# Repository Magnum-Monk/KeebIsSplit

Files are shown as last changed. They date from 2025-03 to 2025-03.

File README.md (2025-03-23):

### Keeb Is Split

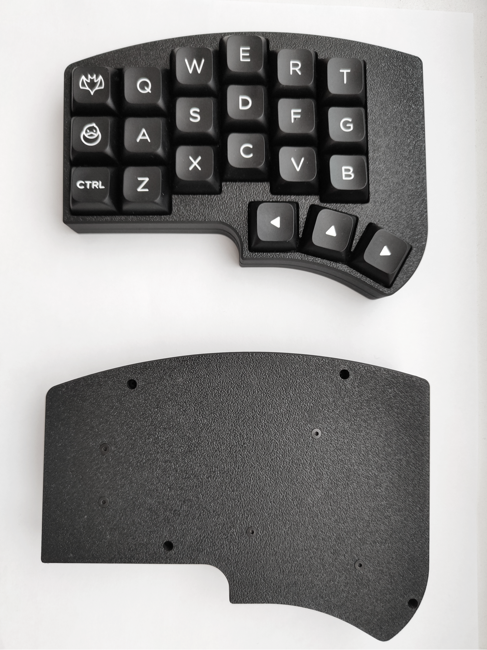
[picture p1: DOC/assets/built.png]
built

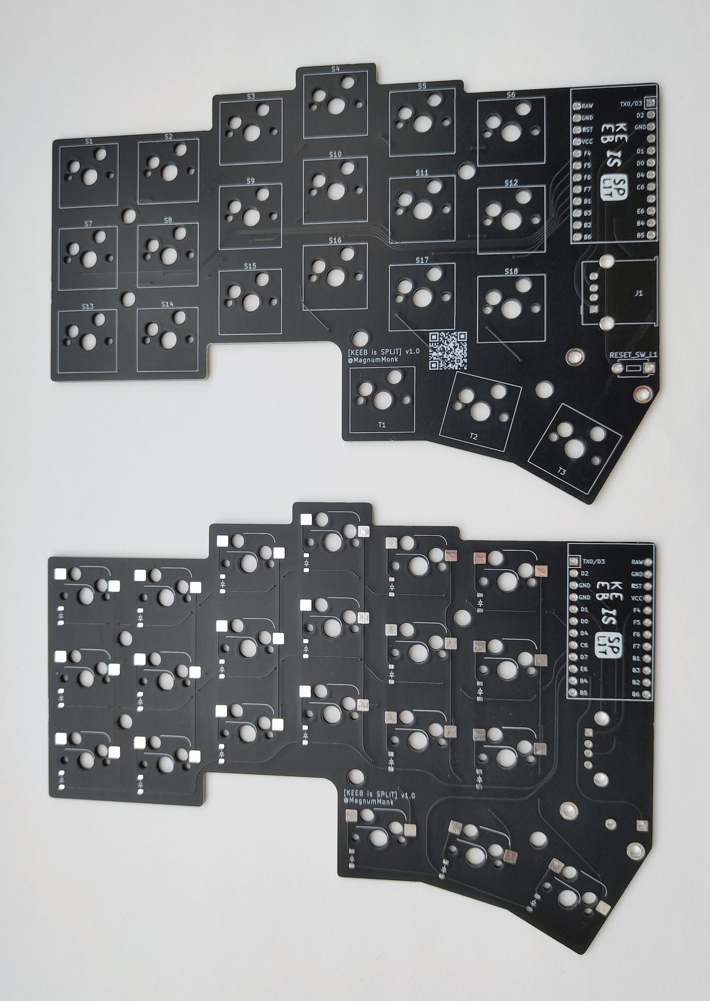
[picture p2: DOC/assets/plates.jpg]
plates


#### Whats the big idea? (TLDR)
Robust, decent-looking, comfortable, cost-effective, easy-to-build/repair/use 3x6 split keyboard. 

#### References / Credits / Inspirations :
- [**CRKBD**](https://github.com/foostan/crkbd) - all-time classic, "industry standart" of DIY ergo keyboards at this point, if I could say so myself;
- [**Cantor/Piantor**](https://github.com/diepala/cantor) - excellent thumb cluster, overall big improvement in layout ergonimics imo.
- [**Altair/Altair-X**](https://www.reddit.com/r/MechanicalKeyboards/comments/1cg4ejp/gb_altairx_live_now_a_premium_easy_to_learn/) - top grade aestethics, build quality.
- [**Cheapino**](https://github.com/tompi/cheapino) - Robust, easy to assemble, easy to fix/repair, easy to source components, well... cheap! ☺️

#### Firmware
This build utilizes exact pinout that **CRKBD** uses. So you can safely use your Corne (v2/v3) firmware to flash this keyboard.
If you've never had a Corne keyboard before, [this](https://github.com/fathulfahmy/corne-keyboard/tree/main/firmware) should work

#### Build guide 
[here](https://github.com/Magnum-Monk/KeebIsSplit/blob/main/DOC/build_guide.md)

#### BOM
| Part | Amount | Links |
|---|---|---|
| ProMicro-like MCU | 2 | [aliexpress](https://aliexpress.com/item/1005004242820623.html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) |
| PCB | 2 | JLCPCB, PCBWay or other service that you prefer |
| MX HotSwap Socket | 42 | [aliexpress](https://aliexpress.com/wholesale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) |
| SMD SOD123 Diode | 42 | [aliexpress](https://www.aliexpress.com/w/wholesale-sod-123-1n4148.html?spm=a2g0o.detail.auto_suggest.3.49e124bT24bTMs) |
| USB-A Socket | 2 | [aliexpress](https://aliexpress.com/item/1005006501690133.html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) |
| USB-A -> USB-A Cable | 1 | [aliexpress 1](https://aliexpress.com/item/1005003574732583.html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) [aliexpress 2](https://aliexpress.com/item/1005006002851777.html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)  [aliexpress 3](https://aliexpress.com/item/1005007351594401.html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) |
| Reset Button | 2 | [aliexpress](https://aliexpress.com/item/1005007177692594.html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) |
| Header Pin Sockets (20 pin) | 4 | [aliexpress](https://aliexpress.com/item/1005005104952508.html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) |
| M2x5 screw | 20 | For attaching mounting plate and bottom case |
| M2x6 screw | 8 | For attaching top case to bottom case |
| M2x5 spacer | 18 | [aliexpress](https://aliexpress.com/item/4000314663724.html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) |
| Top case left | 1 | |
| Top case right | 1 | |
| Bottom case left | 1 | |
| Bottom case right | 1 | |
| Mounting plate left | 1 | |
| Mounting plate right | 1 | |
| Foam mid | 2 | |
| Foam bottom | 2 | |

#### "Why won't you just use one of those referenced options?"
(Basically, a list of nit-picks 😀 )
- **CRKBD** - thumb cluster, specifically 1.5u outermost keys. Not only does it feel a bit clunky for me to use, but also, finding matching keycaps for those keys could be challenging and annoying (and convex 1.5u spacebar is a rarity of its own kind). Although I do somewhat understand the reasoning behind this (design-wise, it makes sense to extend this key to 1.5u, because with 1u you kind of have this "weird" empty corner between this key and the MCU, which for some may look off-putting. Since the mcu is quite wide, you cannot eliminate this issue without moving the whole cluster outwards or rotating it in a werid position, which in and of itself could hurt comfort of use. TRRS connection between two halves.
> Since TRRS safety is quite sensitive and reoccuring topic in the DIY-keyboards community I will not touch it here (or will I?), but I would avoid this option if possible.

- **Cantor / Piantor** - although it is very comfortable to use layout-wise, the MCU board itself is huge, albeit much easier to flash. Which in turn somewhat leaves it with the only option for the halves connection to also be TRRS.
- **Altair/Altair-X** - Not open source. Difficult to repair, if something "dies".  Good luck finding available one to buy these days 😀, not to mention hefty price tag.
- **Cheapino** - RJ45 might be too janky-looking and overall big connector for some users (me included), Otherwise very cool and build-friendly board 🥰.

#### Why not low-profile?

Well, mostly the switches. I am yet to find LP switch, that can compete in typing feel with some remarkable and widely loved MX-type ones. And I have tried almost all chocs, a variety of KS33 and Kailh LP models. The available selection of MX switches at this point is far more superior imo, and could fulfill the needs of any enthusiast. 

#### Why not wireless?
I've tried multiple wireless keyboards, and keeping their charge levels in check is just another hassle for me. And the batteries themselves being another point of failure (experienced quite a few "spicy pillows" myself), which defeats the goal of this being robust. Maybe in the future I'll rethink this, but with the use of 3.7v AAA or coin cell batteries as a power source.

#### Why no LEDs?
I mean... Nothing against it, but it adds nothing of value to the device imo, except, well, cost and build complexity.

#### Why no OLEDs?
Again, I fiddled with them for some time in my Corne keyboards, but at the end I just removed them for the purpose of fitting in a slimmer case. How often do you look at them anyway, while using your device? They're okay to help debugging some build issues with the keyboard, but other than than, just "bells and whistles".

#### Why USB-A connectors? (Oops, I couldn't help myself)

Although its highly debatable, I still think this is the "safe-ish" option to connect two halves of a keyboard:
- Hot pluggable. Finally, no fear of accidentally detaching the cable from your keyboard and frying GPIO, or the whole MCU.
- Low-ish chance of connecting it to the wrong device accidentally, since finding spare USB-A to USB-A cable lying on your desk, connected to some of your devices is highly unlikely (not the case with USB-c, for example). Not to mention, using the same port type to connect keyboard to PC and left MCU to the right MCU can be somewhat confusing, and could easily result in  some MCU damage, being connected improperly).

> But still, please do not use USB-A port on this keyboard to anything other than connecting two halves together. Connecting it to, say, USB port on your PC would most likely damage your MCU, since standard USB port supplies 5v, and MCU is expecting 3.3v.

- Although the selection of available cables is much more limited, than, say, TRRS, there are a lot of options still. And If nothing fits your bill, there are a lot of connectors available to build your own custom cable.

Overall, designing circuitry that supports bi-directional data/power flow with reliable and resilient MCU protection is a challenging task (quite beyond my expertise, tbh), and will definitely significantly complicate assembling process and increase the amount of parts needed (and the price, which is definitely an important factor too).

#### KiCad symbol/footprint libraries used:
- Mostly [scottokeebs](https://github.com/joe-scotto/scottokeebs/tree/main "scottokeebs") ones. Huge props to the guy!
- Also [foostan's](https://github.com/foostan/kbd/tree/f90510c11b6df53bcdb55740b0d59183957e4036) ones

Unfortunately, all 3D files are made in SolidWorks, which is not free/opensource. Maybe someday I'll redo them in FreeCad, but for now it is what it is. STP files for 3D printing (which most slicers should support nowadays) are also included.

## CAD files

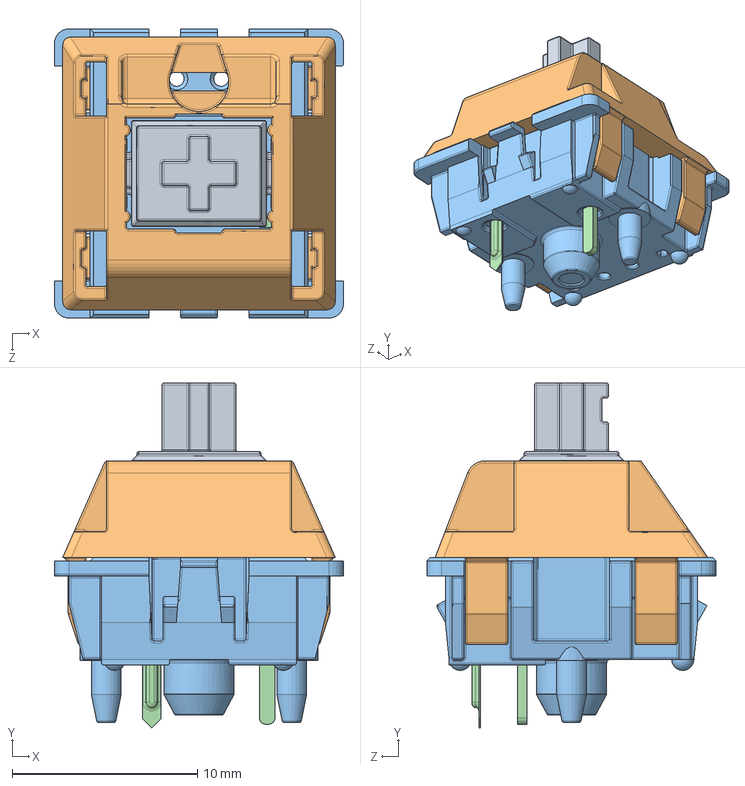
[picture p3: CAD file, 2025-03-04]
3D/MX/MX 按键.SLDASM
15.6 x 18.6 x 15.6 mm
MX 轴 按键
MX 轴 轴体
MX轴 轴体 底部
针脚

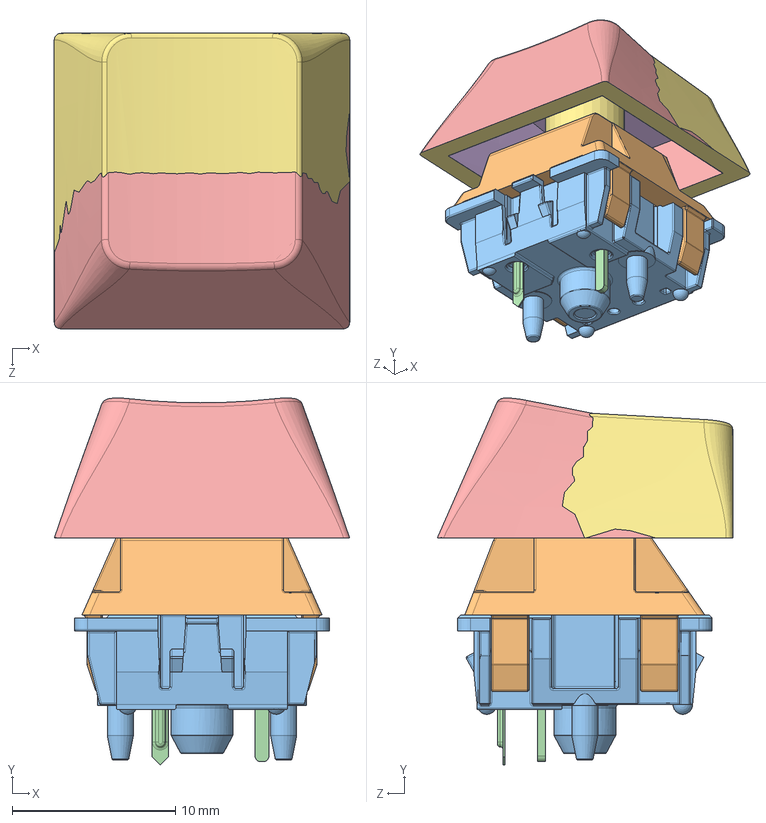
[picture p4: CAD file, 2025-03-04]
3D/MX/MX_SWITCH.SLDASM
18.1 x 22.5 x 18.1 mm
MX 轴 按键
MX 轴 轴体
MX轴 轴体 底部
针脚
r2_100

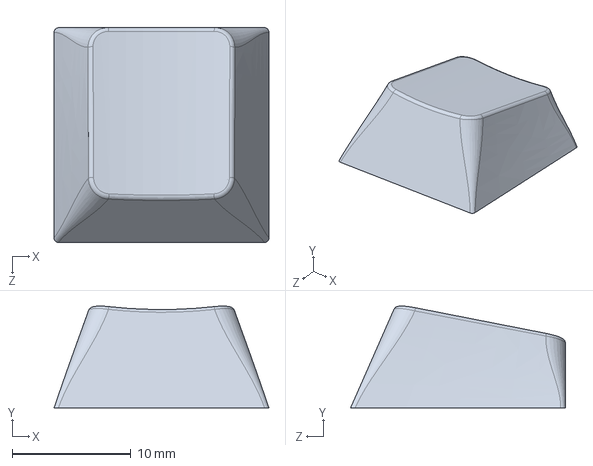
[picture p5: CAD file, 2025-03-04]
3D/MX/r4_100.SLDPRT
18.1 x 8.58 x 18.1 mm

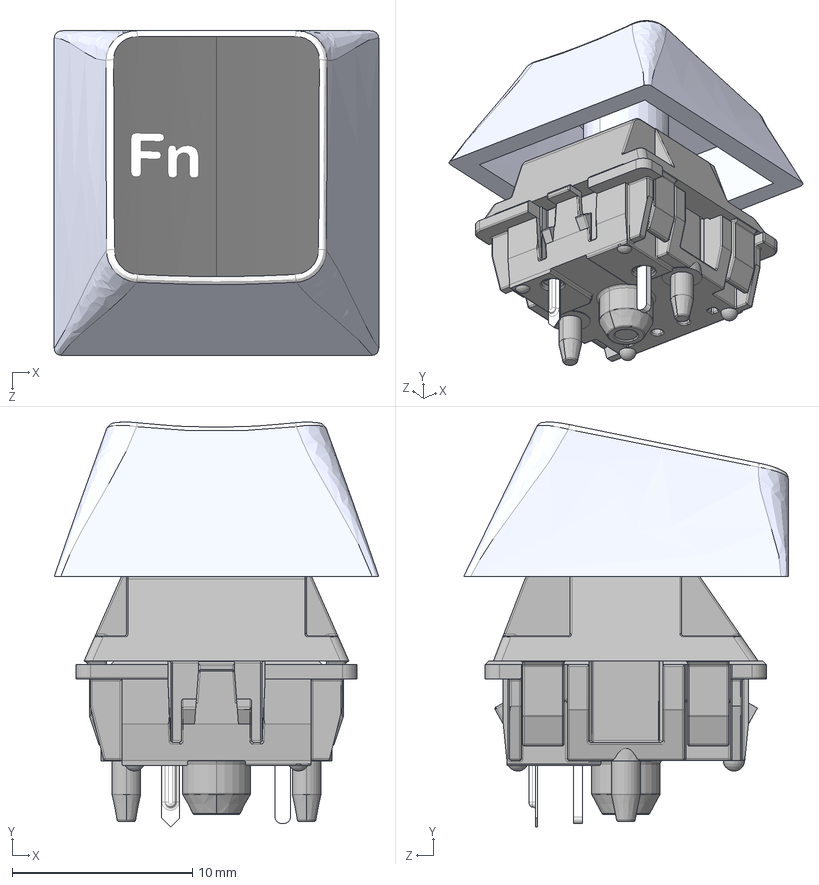
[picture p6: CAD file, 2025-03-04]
3D/MX_R4.STEP
18.0 x 22.5 x 18.0 mm
MX 轴 按键
MX 轴 轴体
MX轴 轴体 底部_默认
针脚_默认
Fn.stp

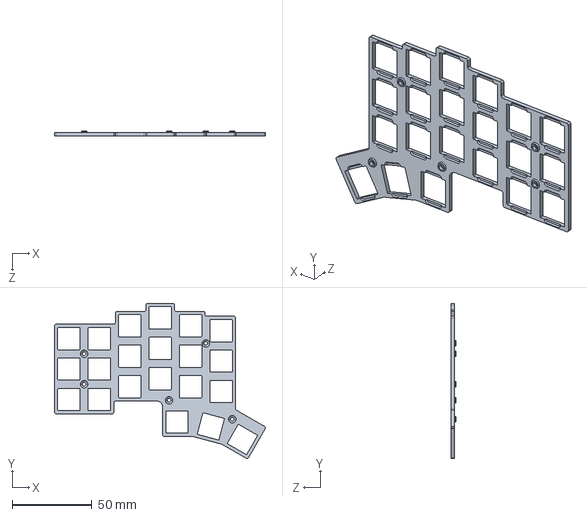
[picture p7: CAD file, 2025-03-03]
3D/STP/PLATE.STP
132.1 x 97.1 x 2.90 mm

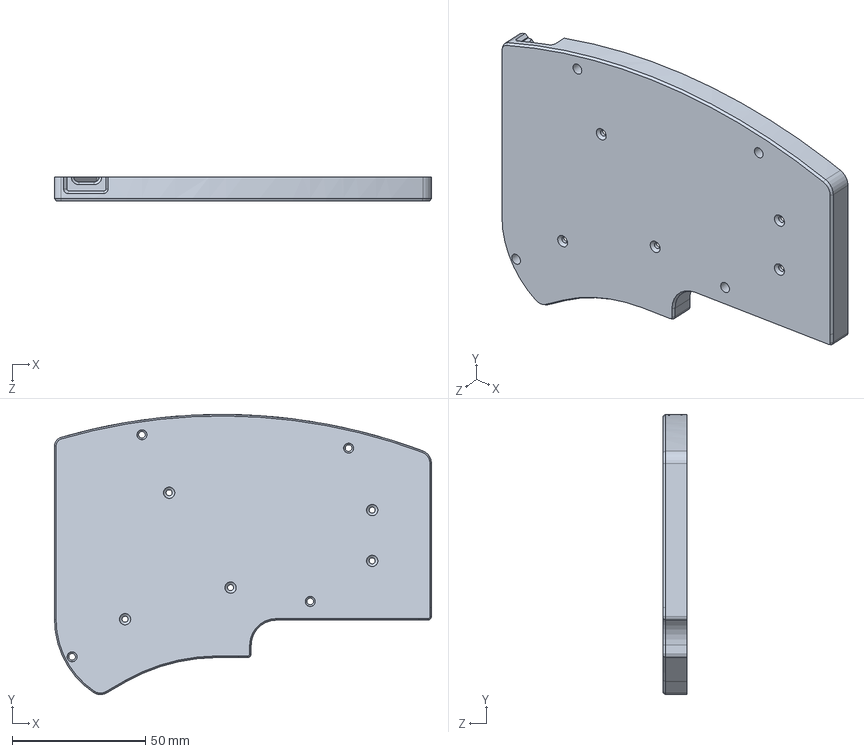
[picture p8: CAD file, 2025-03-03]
3D/CASE_LEFT_BOT.SLDPRT
141.5 x 105.2 x 9.05 mm

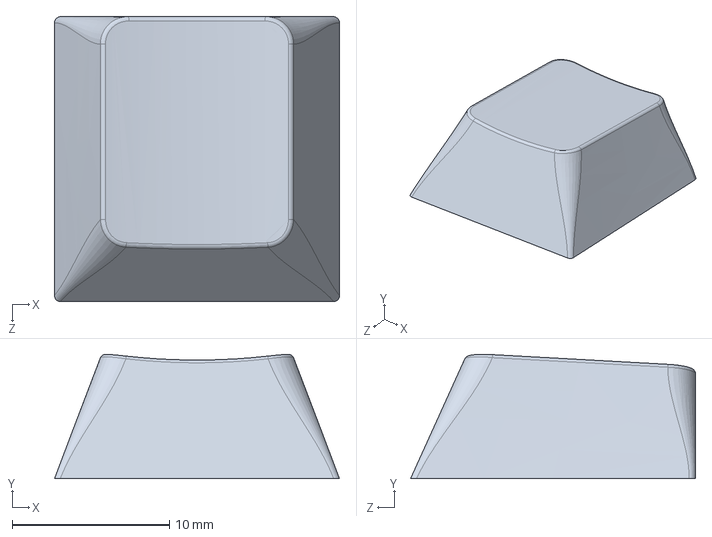
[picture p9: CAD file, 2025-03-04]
3D/MX/r2_100.SLDPRT
18.1 x 7.89 x 18.1 mm

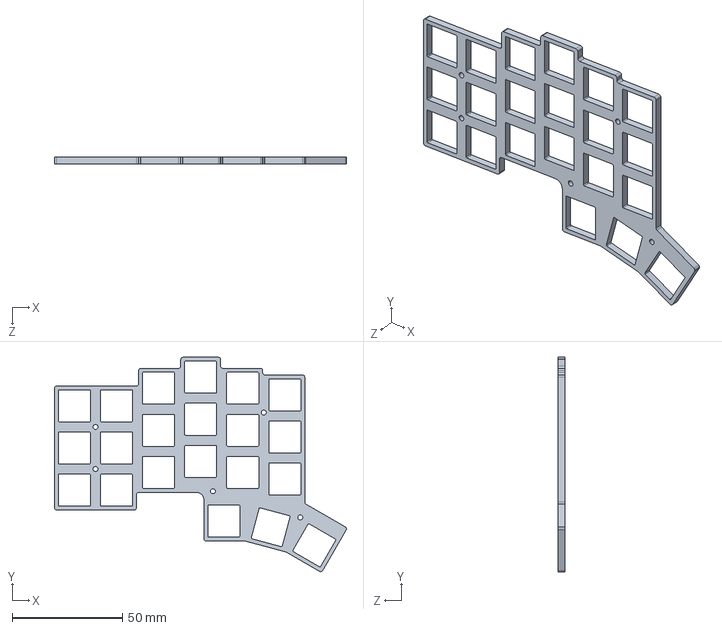
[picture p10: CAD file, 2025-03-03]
3D/STP/EVA_MID.STP
132.2 x 97.1 x 3.00 mm

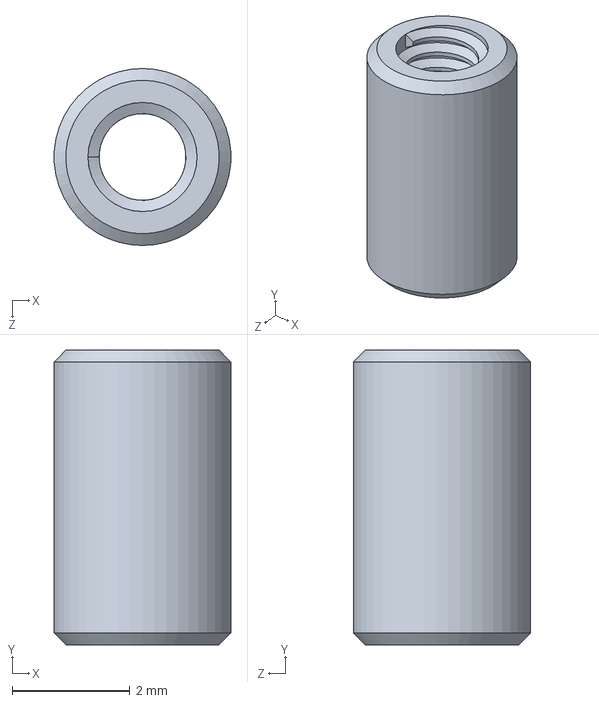
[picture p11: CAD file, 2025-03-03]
3D/M2_SPACER.SLDPRT
2.99 x 5.00 x 3.00 mm

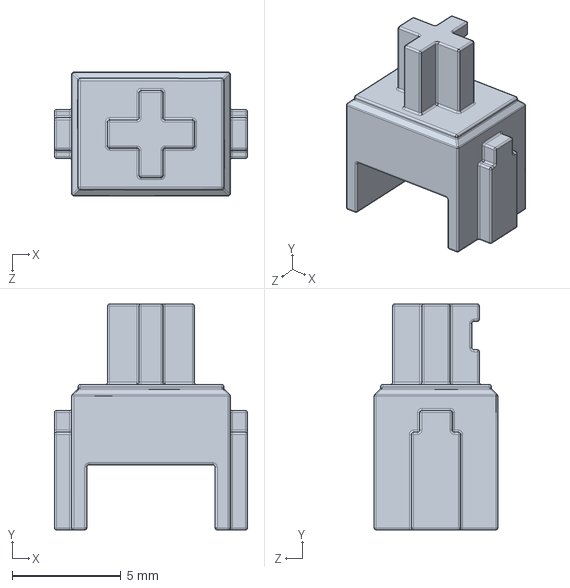
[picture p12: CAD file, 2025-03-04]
3D/MX/MX 轴 按键.SLDPRT
8.90 x 10.4 x 5.70 mm

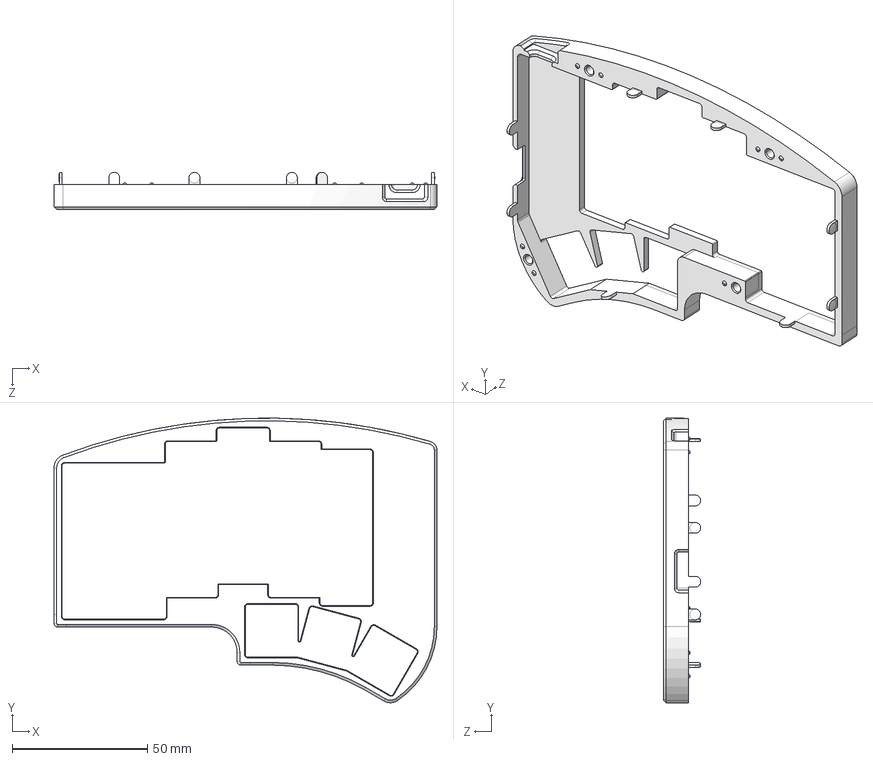
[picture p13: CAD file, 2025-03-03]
3D/STP/CASE_LEFT_TOP.STP
141.5 x 105.1 x 13.8 mm

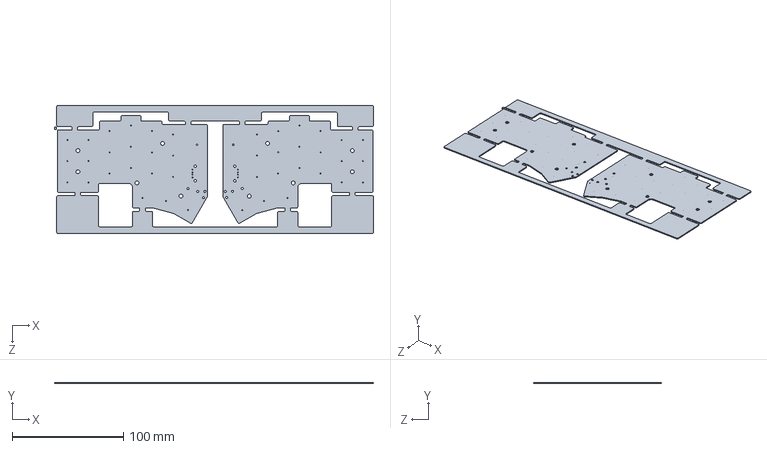
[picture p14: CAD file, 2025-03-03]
3D/edge cuts.SLDPRT
287.0 x 1.00 x 115.1 mm

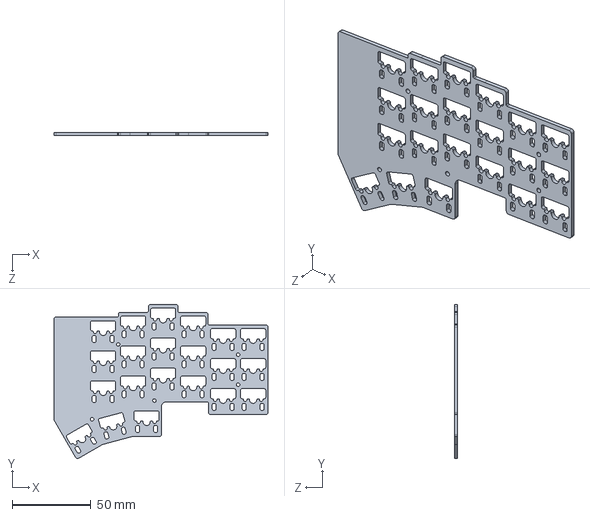
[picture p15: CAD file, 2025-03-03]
3D/STP/EVA_BOTTOM.STP
135.9 x 97.9 x 2.00 mm

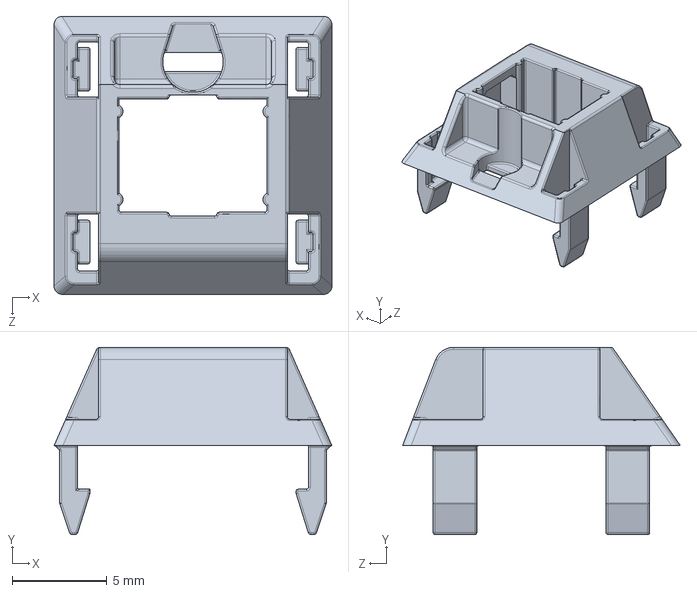
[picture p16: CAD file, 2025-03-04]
3D/MX/MX 轴 轴体.SLDPRT
14.7 x 9.90 x 14.7 mm

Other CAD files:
3D/STP/CASE_LEFT_BOT_CLIPS.STP
3D/ATMEGA32U4_TYPE_C.SLDPRT
3D/MX/针脚.SLDPRT
3D/MX/MX轴 轴体 底部.SLDPRT
3D/CASE_LEFT_BOT_CLIPS.SLDPRT
3D/CASE_LEFT_TOP.SLDPRT
3D/EVA_BOTTOM.SLDPRT
3D/EVA_MID.SLDPRT
3D/MX/r3_100.SLDPRT
3D/PLATE.SLDPRT
3D/SCREW_M2.SLDPRT

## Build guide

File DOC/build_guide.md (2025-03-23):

### Keeb is Split v1 Build Guide

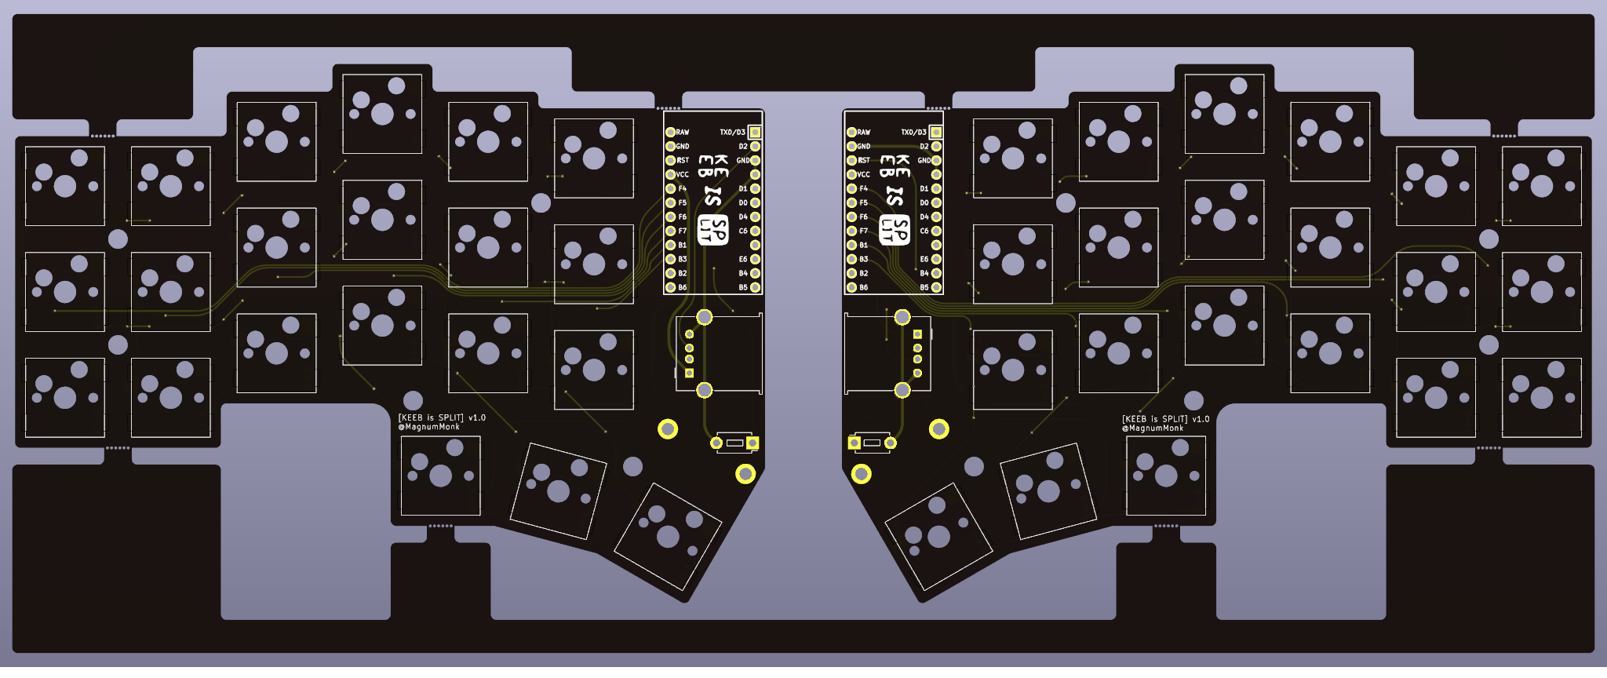
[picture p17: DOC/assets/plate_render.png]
plate


1) First, break/cut the panels off in places, marked here

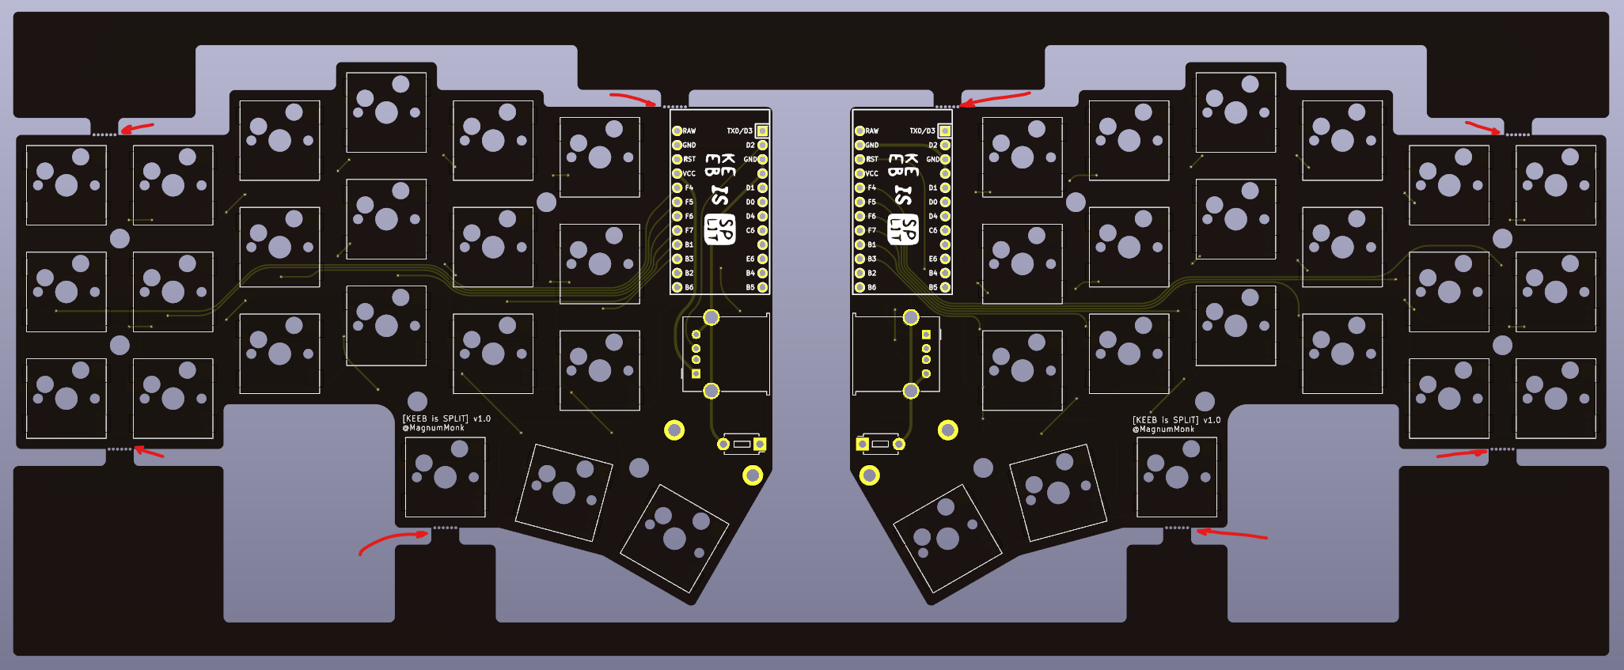
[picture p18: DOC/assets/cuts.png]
cut


2) Next - soldering. I would suggest starting with hotswap MX sockets. Follow the footprint markings on PCB

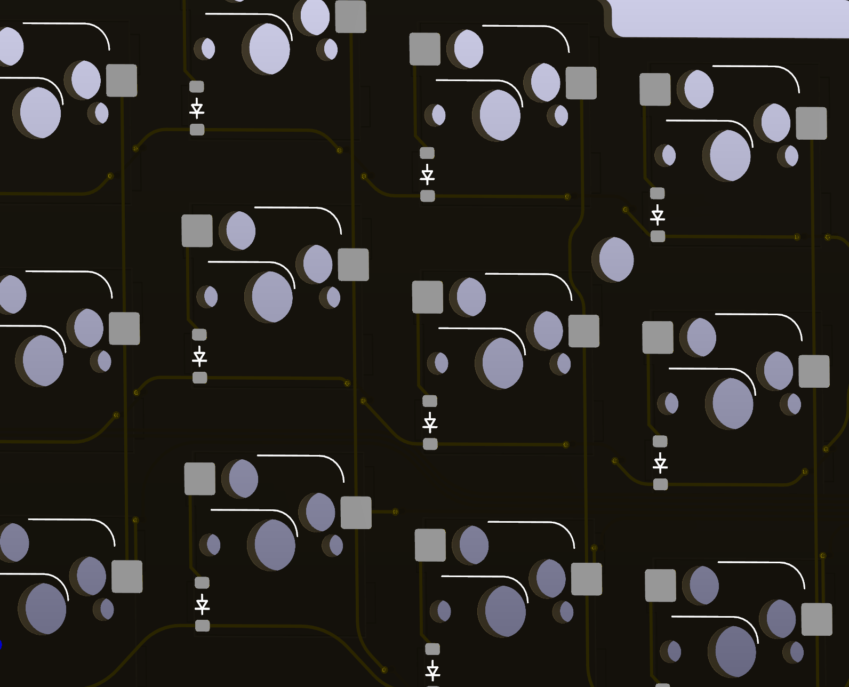
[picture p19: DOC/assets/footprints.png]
footprints

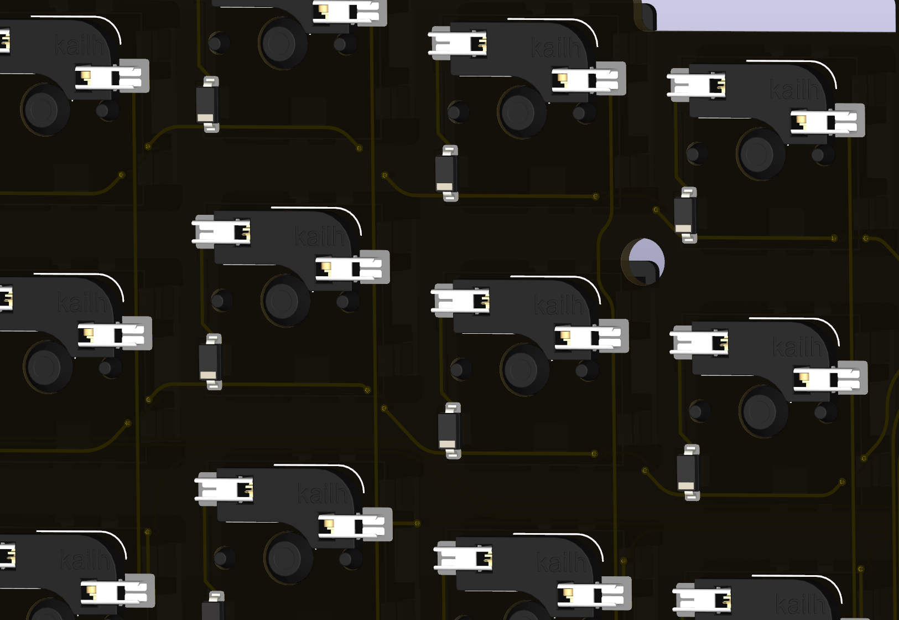
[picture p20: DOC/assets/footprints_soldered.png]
footprints_soldered


3) Now solder the SMD Diodes. You got multiple options here.
 - Using soldering paste with hot air gun
 - Using regular solder wire with soldering iron
   
 I won't go in depth on this here, but you can easily find more info on SMD soldering online, [for example](https://www.instructables.com/A-Complete-Beginners-Guide-to-SMD-Soldering/)                                                                                                                   

 I went with the second option. Little tip:
 First put some solder on one of the pads, pick up the Diode with some tweezers. Position it correctly - the markings on the diode should have a stripe, that should be aligned with marking on the pcb itself.
 Next, heat up the pad with solder on it, and carefully slide in the diode leg into solder. Reheat the solder and tweak the positioning of the diode if necessary.
 Here's an image for more clarity: 

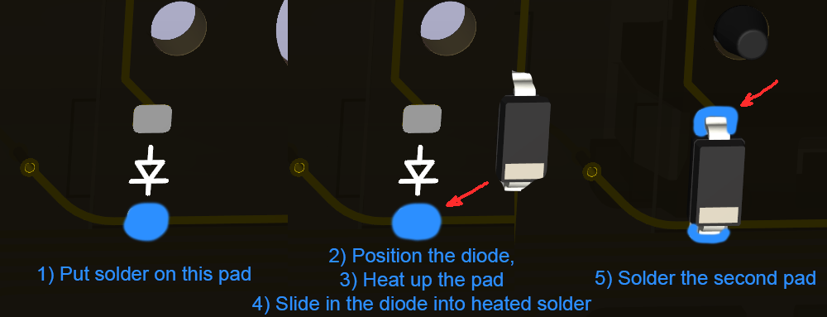
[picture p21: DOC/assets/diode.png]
diode


After all's done, it should look something like this:

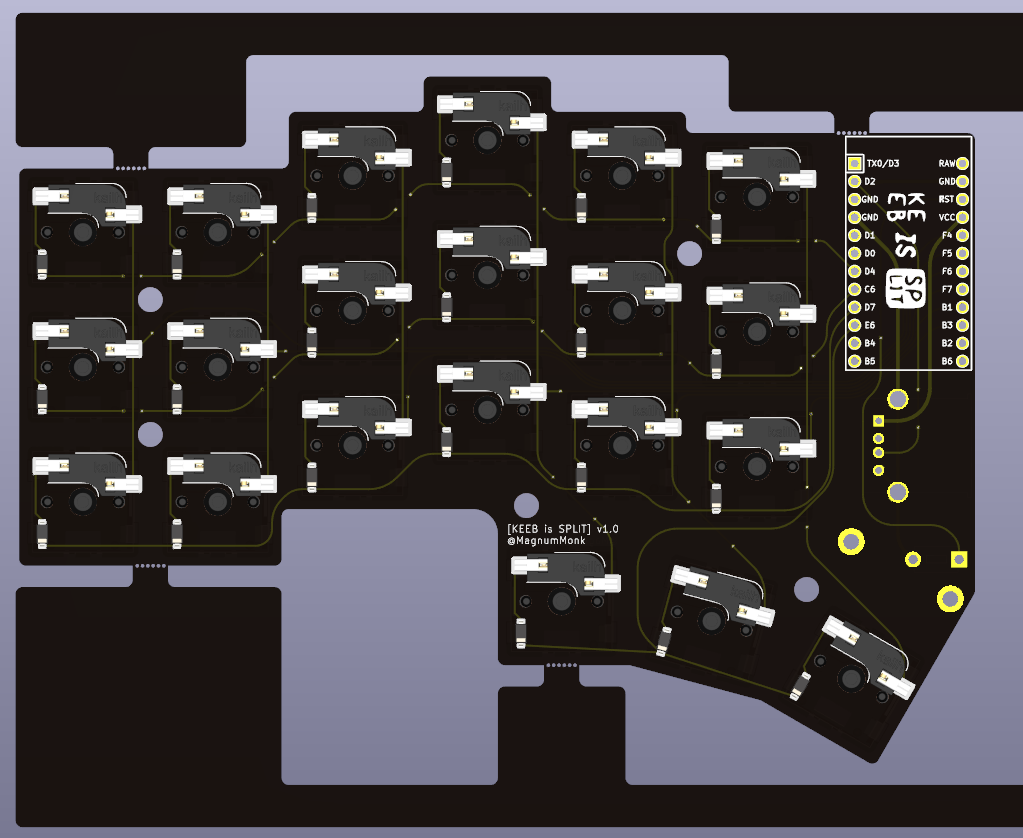
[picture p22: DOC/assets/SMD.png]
SMD


4) Next step is to solder through-hole parts. That being USB-A sockets and reset buttons. Nothing crazy here, just follow the PCB footprint markings.
Little notice - depending on the components you might want to cut off its legs, that extend more than 2mm from the PCB, since they might collide with the case bottom otherwise

5) Soldering the MCU Boards.

If you are planning to use the case, provided with this build, I would highly suggest bying exact pin sockets, mentioned in BOM list in main readme.md file, since the case is designed around using them.

First, cut off the sockets to 12-pin size, You'll need 4 of those. Then prepare some pins of your choice (do not use pins that come with the MCU itself, since they're not compatible with MCU sockets used here). I used spare through hole diode legs, some 0.6mm copper wire would work too. In some previous builds I used copper wire from twisted pair internet cable, that would do too.
Then insert sockets into PCB holes, or better yet - use some "breadboard" if you have one, since there would be no play, and MCU alignment would be much better. Put the MCU board facing down on the sockets, insert your pins through MCU board into sockets.

Should look like this:

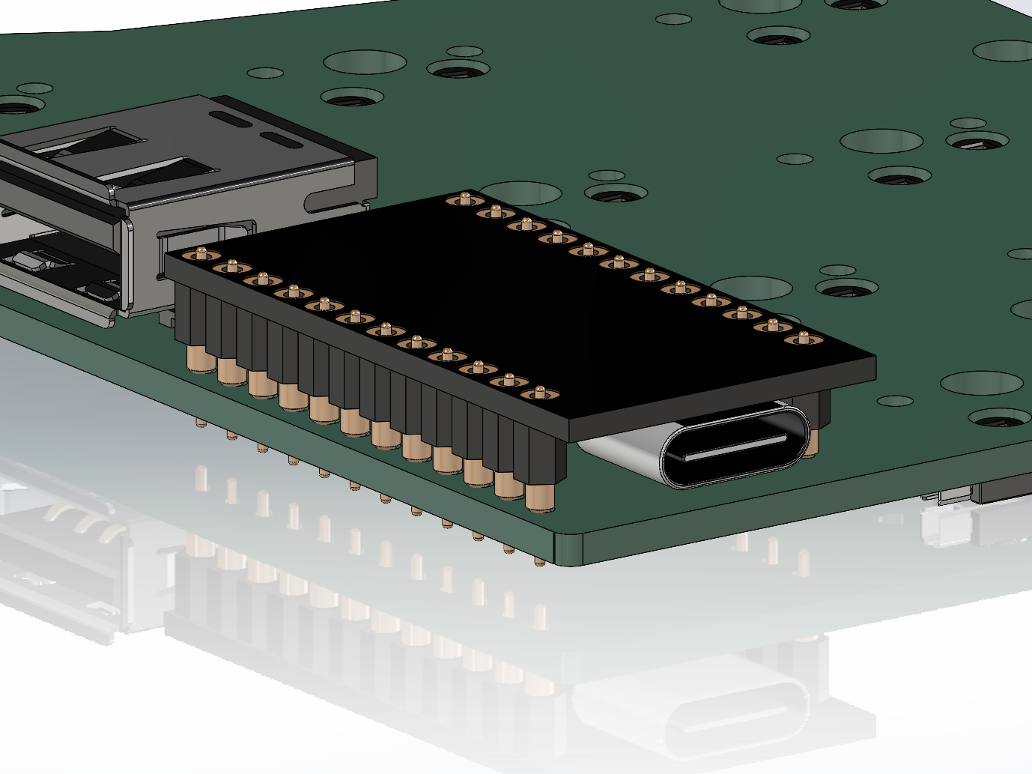
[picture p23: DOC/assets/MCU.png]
MCU


Next. Solder the pins on the MCU. While soldering, keep checking if there are no gaps between MCU and the sockets. I would suggest soldering outermost pins first, and then reseating the MCU (if needed) by reheating said pins while pressing down on the MCU slightly. Try to solder the pins in "cross" pattern, to minimize the unnecessary tension caused by thermal extention of the board. I usually go with top-right -> bottom-left -> top-left -> bottom-right, then center pins, then repeat until all pins are soldered.

Flip the PCB and repeat the same process with socket pins. Again, try to keep the socket headers pushed into the PCB as much as possible to have no gaps between them.

6) Flash the firmware if you haven't already, and you're good to go.

#### Case assembly
Next steps are only needed if you opted for using provided case.

7) First, you need to install m2x5 standoffs into the top case. Mounting holes for them are reasonably spacious, but fitting might be inconsistent depending on print quality/plastic e.t.c. 
Try to insert a standoff into each hole to check how it fits. In my case outermost holes shrunk too much after printing, and I had to use some sanding on the standoffs to fit them in. Those could be tight-fit, no additional adhesive needed.
The rest were fitting nicely, but I still opted for super glue to hold them in place. Little tip: pick up a standoff, screw in an m2 screw into it, apply thin coating of glue on the side of a standoff, carefully insert in into the case, use the screw as a handle to position a standoff inside the case, check if glue has set, then unscrew and repeat. You can install them flush, or slightly "submerged", just check if they're not protruding, to avoid gaps between top and bottom cases.

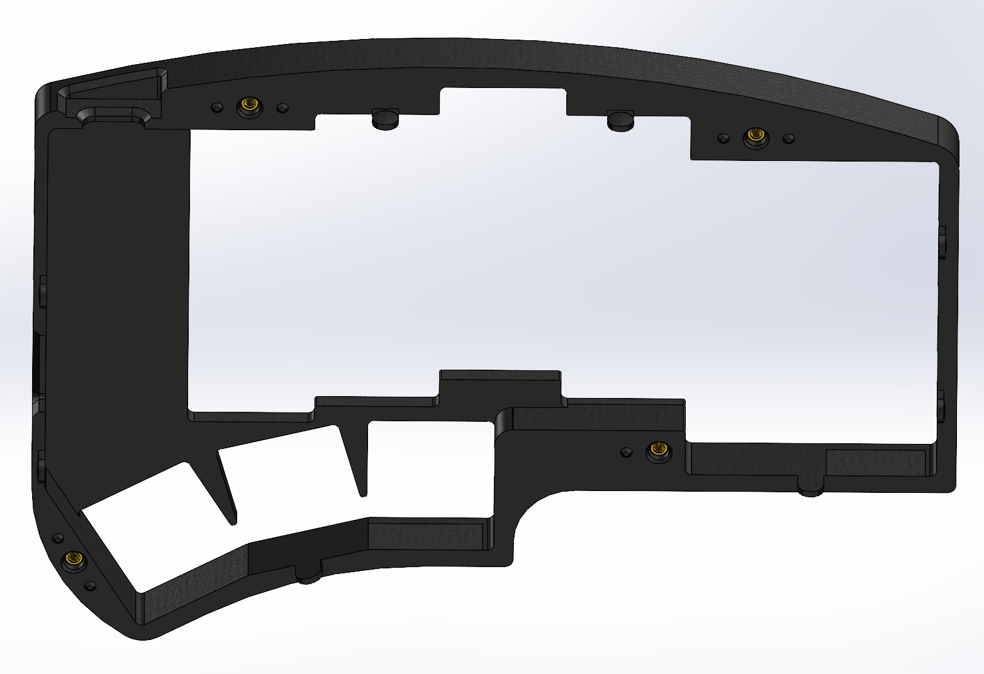
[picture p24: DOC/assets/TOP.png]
TOP


8) Screw in m2x5 standoffs to the bottom case with m2x5 screws.

7) (optional) Put in bottom dampening foam in the case, using previously installed standoffs as a guide.

8) Next, place the assembled PCB into the case.

9) (optional) Put in the middle dampening foam on the PCB

10) Screw in switch mounting plate to the standoffs on the bottom case.

Here's a simplified assembly to use as a rough guide:

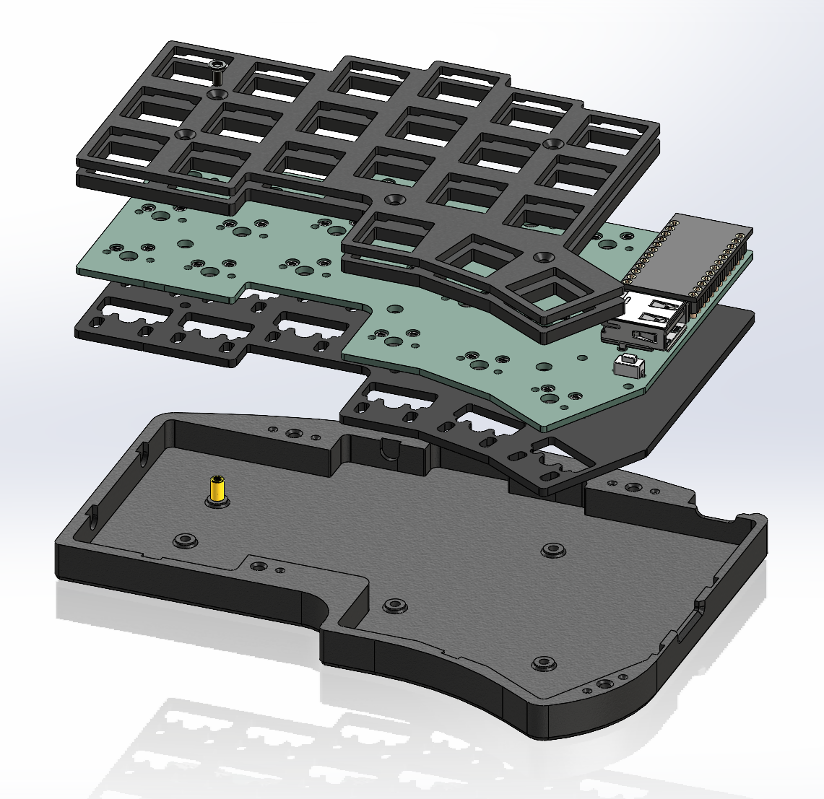
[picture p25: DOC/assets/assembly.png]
assembly


In this stage it is a good idea to check if everything fits nicely together. Try on the top case and check if all the USB-C / USB-A holes are positioned correctly. It is essential to follow step 5 thoroughly to be sure that MCU USB-C port is aligned vertically with the case opening for it, as it could be tricky to fix it after sockets are already soldered onto the PCB. Moreover, some ProMicro clones have inconsistent USB-C port positioning, so that is something you should keep in mind too. In a worst case scenario you can always use a file to adjust the case opening, noone is gonna judge you :)

11) If everything is okay, put in your favorite switches and keycaps and screw the top case to the bottom case using m2x6 ~ m2x8 screws.

Et voila!

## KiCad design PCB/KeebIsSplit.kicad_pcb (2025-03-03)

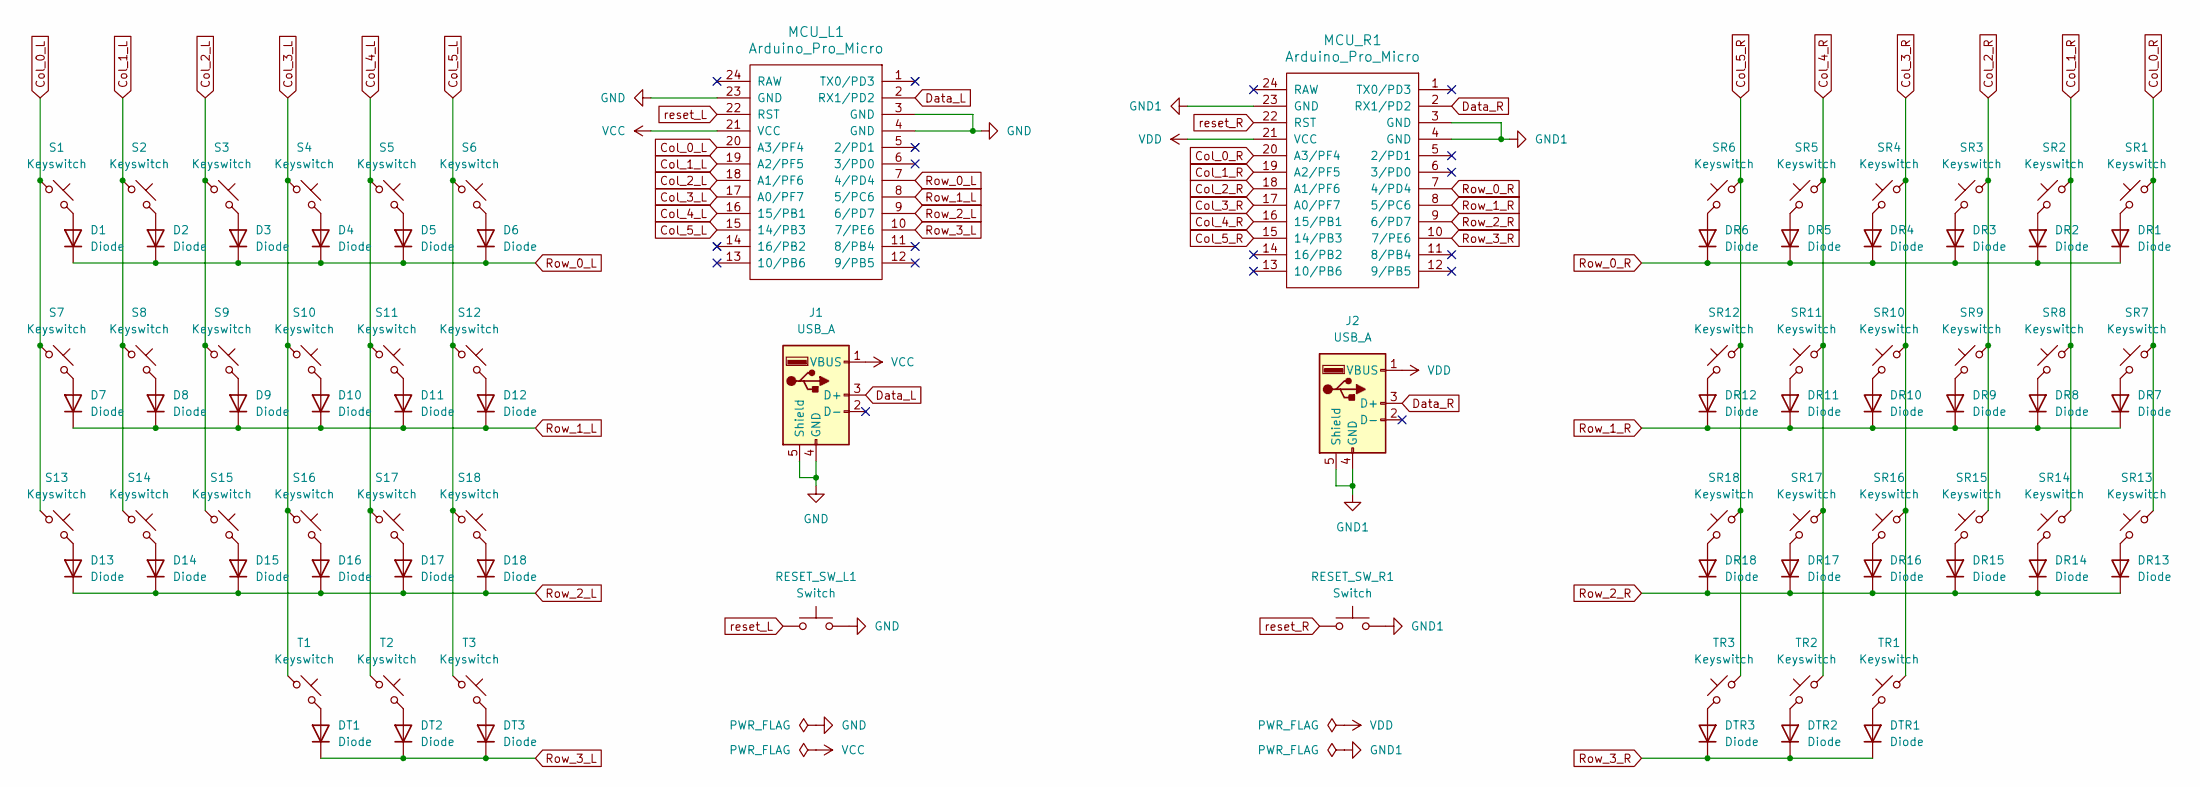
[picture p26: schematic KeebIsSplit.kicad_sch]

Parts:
D1, D2, D3, D4, D5, D6, D7, D8, D9, D10, D11, D12, D13, D14, D15, D16, D17, D18: Diode; Diode_SOD-123
DR1, DR2, DR3, DR4, DR5, DR6, DR7, DR8, DR9, DR10, DR11, DR12, DR13, DR14, DR15, DR16, DR17, DR18: Diode; Diode_SOD-123
DT1, DT2, DT3: Diode; Diode_SOD-123
DTR1, DTR2, DTR3: Diode; Diode_SOD-123
J1, J2: USB_A; USB_A_Molex_67643_Horizontal
MCU_L1: Arduino_Pro_Micro
MCU_R1: Arduino_Pro_Micro
RESET_SW_L1: Switch; Button_MJTP1243
RESET_SW_R1: Switch; Button_MJTP1243
S1, S2, S3, S4, S5, S6, S7, S8, S9, S10, S11, S12, S13, S14, S15, S16, S17, S18: Keyswitch; Hotswap_MX_1.00u
SR1, SR2, SR3, SR4, SR5, SR6, SR7, SR8, SR9, SR10, SR11, SR12, SR13, SR14, SR15, SR16, SR17, SR18: Keyswitch; Hotswap_MX_1.00u
T1, T2, T3: Keyswitch; Hotswap_MX_1.00u
TR1, TR2, TR3: Keyswitch; Hotswap_MX_1.00u

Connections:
Col_0_L: MCU_L1.20 (A3/PF4), S1.1, S7.1, S13.1
Col_0_R: MCU_R1.20 (A3/PF4), SR1.1, SR7.1, SR13.1
Col_1_L: MCU_L1.19 (A2/PF5), S2.1, S8.1, S14.1
Col_1_R: MCU_R1.19 (A2/PF5), SR2.1, SR8.1, SR14.1
Col_2_L: MCU_L1.18 (A1/PF6), S3.1, S9.1, S15.1
Col_2_R: MCU_R1.18 (A1/PF6), SR3.1, SR9.1, SR15.1
Col_3_L: MCU_L1.17 (A0/PF7), S4.1, S10.1, S16.1, T1.1
Col_3_R: MCU_R1.17 (A0/PF7), SR4.1, SR10.1, SR16.1, TR1.1
Col_4_L: MCU_L1.16 (15/PB1), S5.1, S11.1, S17.1, T2.1
Col_4_R: MCU_R1.16 (15/PB1), SR5.1, SR11.1, SR17.1, TR2.1
Col_5_L: MCU_L1.15 (14/PB3), S6.1, S12.1, S18.1, T3.1
Col_5_R: MCU_R1.15 (14/PB3), SR6.1, SR12.1, SR18.1, TR3.1
Data_L: J1.3 (D+), MCU_L1.2 (RX1/PD2)
Data_R: J2.3 (D+), MCU_R1.2 (RX1/PD2)
GND: J1.4 (GND), J1.5 (Shield), MCU_L1.3 (GND), MCU_L1.4 (GND), MCU_L1.23 (GND), RESET_SW_L1.2
GND1: J2.4 (GND), J2.5 (Shield), MCU_R1.3 (GND), MCU_R1.4 (GND), MCU_R1.23 (GND), RESET_SW_R1.2
unnamed: D1.2 (A), S1.2
unnamed: D2.2 (A), S2.2
unnamed: D3.2 (A), S3.2
unnamed: D4.2 (A), S4.2
unnamed: D5.2 (A), S5.2
unnamed: D6.2 (A), S6.2
unnamed: D7.2 (A), S7.2
unnamed: D8.2 (A), S8.2
unnamed: D9.2 (A), S9.2
unnamed: D10.2 (A), S10.2
unnamed: D11.2 (A), S11.2
unnamed: D12.2 (A), S12.2
unnamed: D13.2 (A), S13.2
unnamed: D14.2 (A), S14.2
unnamed: D15.2 (A), S15.2
unnamed: D16.2 (A), S16.2
unnamed: D17.2 (A), S17.2
unnamed: D18.2 (A), S18.2
unnamed: DR1.2 (A), SR1.2
unnamed: DR2.2 (A), SR2.2
unnamed: DR3.2 (A), SR3.2
unnamed: DR4.2 (A), SR4.2
unnamed: DR5.2 (A), SR5.2
unnamed: DR6.2 (A), SR6.2
unnamed: DR7.2 (A), SR7.2
unnamed: DR8.2 (A), SR8.2
unnamed: DR9.2 (A), SR9.2
unnamed: DR10.2 (A), SR10.2
unnamed: DR11.2 (A), SR11.2
unnamed: DR12.2 (A), SR12.2
unnamed: DR13.2 (A), SR13.2
unnamed: DR14.2 (A), SR14.2
unnamed: DR15.2 (A), SR15.2
unnamed: DR16.2 (A), SR16.2
unnamed: DR17.2 (A), SR17.2
unnamed: DR18.2 (A), SR18.2
unnamed: DT1.2 (A), T1.2
unnamed: DT2.2 (A), T2.2
unnamed: DT3.2 (A), T3.2
unnamed: DTR1.2 (A), TR1.2
unnamed: DTR2.2 (A), TR2.2
unnamed: DTR3.2 (A), TR3.2
Row_0_L: D1.1 (K), D2.1 (K), D3.1 (K), D4.1 (K), D5.1 (K), D6.1 (K), MCU_L1.7 (4/PD4)
Row_0_R: DR1.1 (K), DR2.1 (K), DR3.1 (K), DR4.1 (K), DR5.1 (K), DR6.1 (K), MCU_R1.7 (4/PD4)
Row_1_L: D7.1 (K), D8.1 (K), D9.1 (K), D10.1 (K), D11.1 (K), D12.1 (K), MCU_L1.8 (5/PC6)
Row_1_R: DR7.1 (K), DR8.1 (K), DR9.1 (K), DR10.1 (K), DR11.1 (K), DR12.1 (K), MCU_R1.8 (5/PC6)
Row_2_L: D13.1 (K), D14.1 (K), D15.1 (K), D16.1 (K), D17.1 (K), D18.1 (K), MCU_L1.9 (6/PD7)
Row_2_R: DR13.1 (K), DR14.1 (K), DR15.1 (K), DR16.1 (K), DR17.1 (K), DR18.1 (K), MCU_R1.9 (6/PD7)
Row_3_L: DT1.1 (K), DT2.1 (K), DT3.1 (K), MCU_L1.10 (7/PE6)
Row_3_R: DTR1.1 (K), DTR2.1 (K), DTR3.1 (K), MCU_R1.10 (7/PE6)
VCC: J1.1 (VBUS), MCU_L1.21 (VCC)
VDD: J2.1 (VBUS), MCU_R1.21 (VCC)
reset_L: MCU_L1.22 (RST), RESET_SW_L1.1
reset_R: MCU_R1.22 (RST), RESET_SW_R1.1

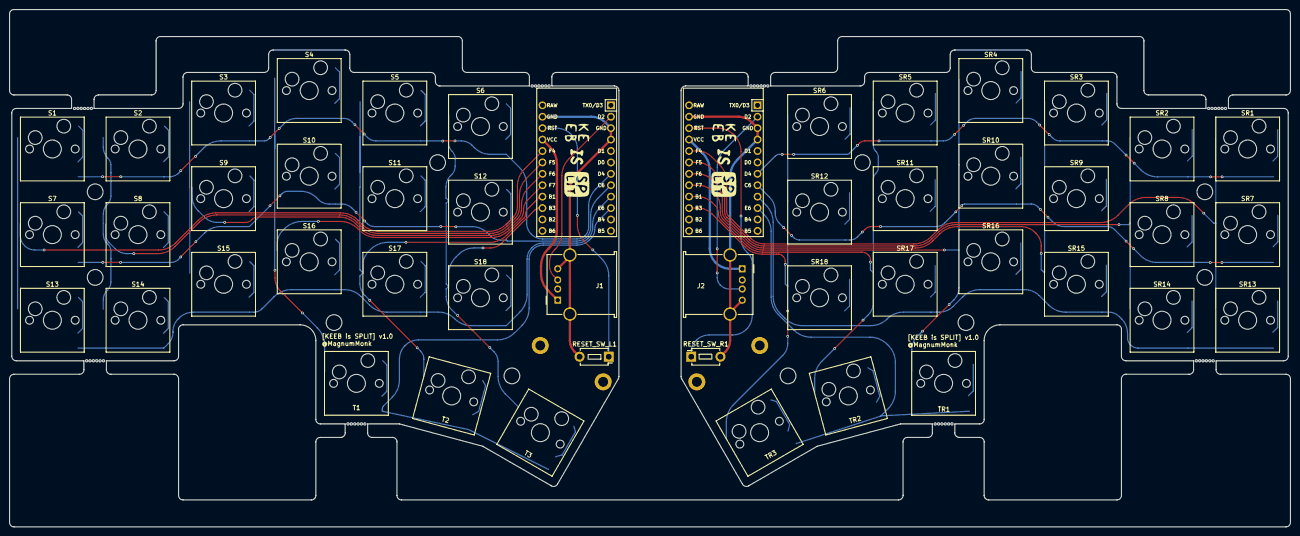
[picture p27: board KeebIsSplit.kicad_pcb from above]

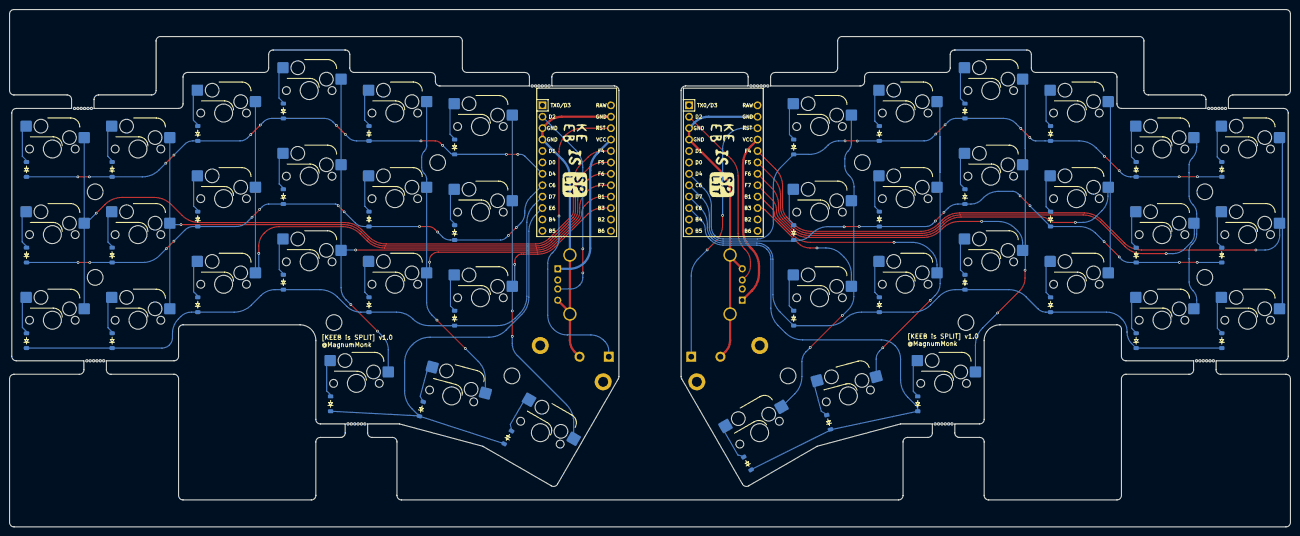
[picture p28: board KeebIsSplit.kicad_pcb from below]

Board: 2 copper layers, 285.0 x 115.1 mm, 90 parts (44 on the bottom side), 70 nets.

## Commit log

2025-03-03 Add PCB files
    [KeebIsSplit.kicad_pcb, KeebIsSplit.kicad_sch]
2025-03-03 Add Gerber files
    [KeebIsSplit-B_Cu.gbr, KeebIsSplit-B_Mask.gbr, KeebIsSplit-B_Paste.gbr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]
2025-03-03 Add 3D files
    [ATMEGA32U4_TYPE_C.SLDPRT, CASE_LEFT_BOT.SLDPRT, CASE_LEFT_BOT_CLIPS.SLDPRT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]
2025-03-04 Add 3D models of MX switches with keycaps
    [MX 按键.SLDASM, MX 轴 按键.SLDPRT, MX 轴 轴体.SLDPRT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]
2025-03-04 Add keys to thumb cluster in assembly
2025-03-28 Increase the MX mounting hole by .1mm
    [PLATE.SLDPRT]
2025-03-28 Update the assembly
